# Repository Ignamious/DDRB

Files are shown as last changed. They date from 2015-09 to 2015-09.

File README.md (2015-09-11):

# DDRB 
This is a Digital Decade Resistor Box. This is the same as a Decade Resistor box, but uses an Arduino with LCD and Keypad to set the value. This will also allow the user to check the box and insure it's still within spec.

List of Features
  - LCD Readout of Resistance
  - Keypad to set resistance
  - Sub Ohm of .01 - .99 
  - Ohm 2^30 of Resistance ≈ 1,073,741,824 Ohms
  - Modular Cards, Easily replacable for Increased precistion (with Increase of Cst to the board)
  - 2 Expanstion Slots, Each with three Pins to the MCU (Future Expanstion) Signal Does Pass through these.
    - Possible uses
      - reading resistance from start to finish (will require slight rework of Buss Board)
      - Altering Resistance to give "True" value
      - Pulsed Output such as Sig Gen using Resistance values.
  - uses Binary Resistance values to get final resuslts:
    - 1 ohm + 2 ohm + 8 ohm = 11 ohms of resistance ECT. 
      - Should reduce cost

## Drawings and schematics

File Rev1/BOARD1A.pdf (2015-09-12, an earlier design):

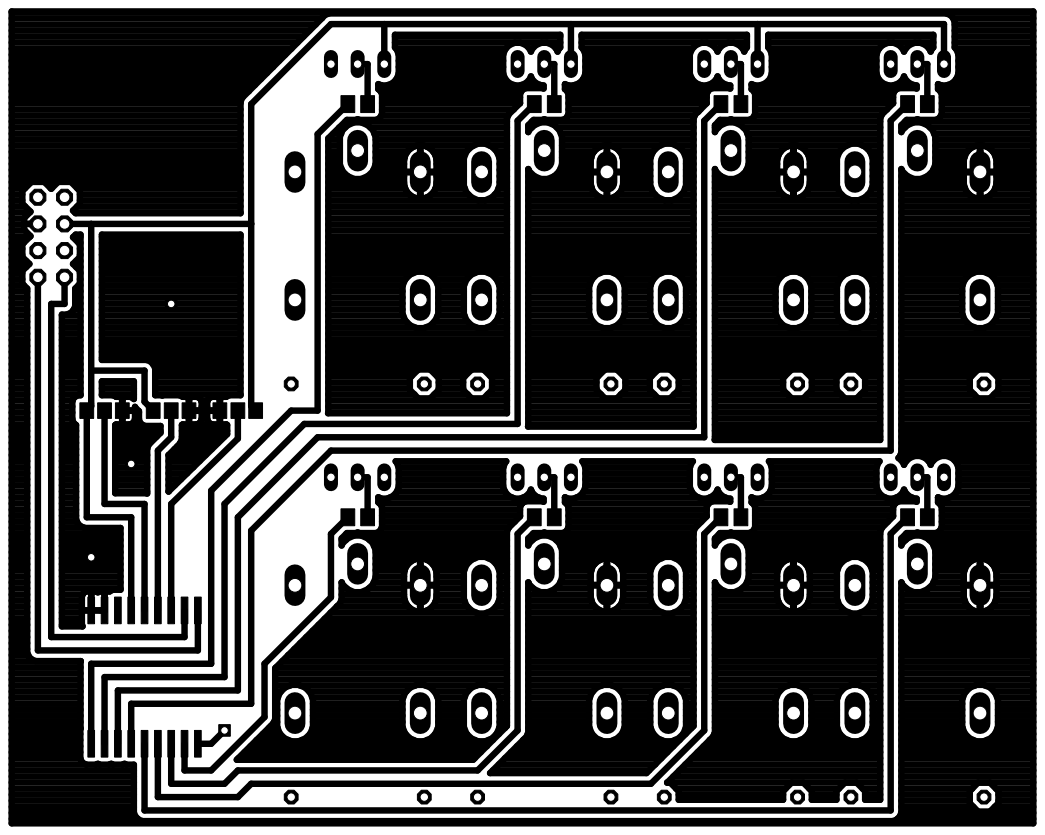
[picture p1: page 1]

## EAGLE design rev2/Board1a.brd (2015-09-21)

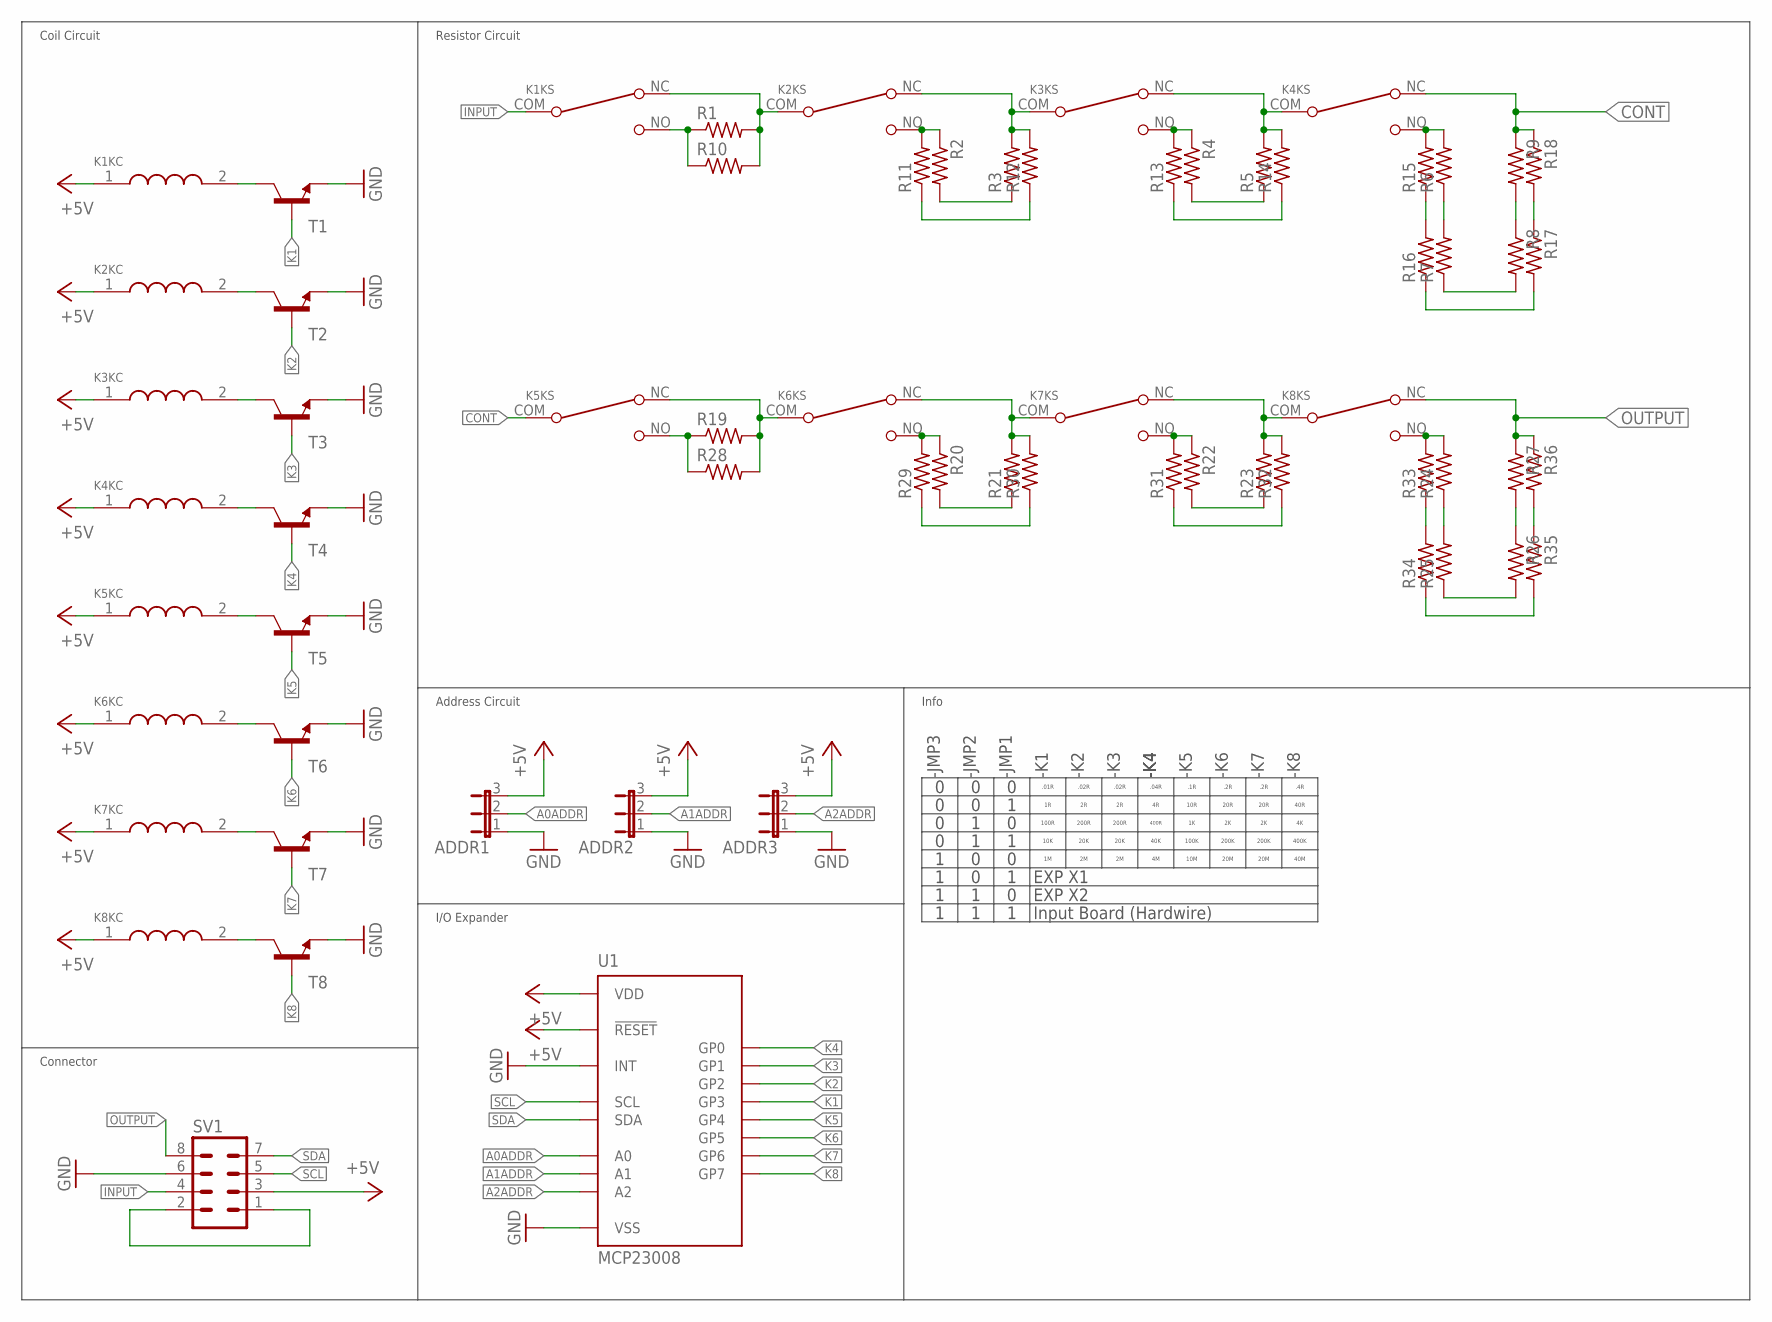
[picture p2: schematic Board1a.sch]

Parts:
ADDR1, ADDR2, ADDR3: JP2E; JP2
K1, K5: G5LE-1-VD DC12; G5LE
K2, K3, K4, K6, K7, K8: G5LE
R1, R2, R3, R4, R5, R6, R7, R8, R9, R19, R20, R21, R22, R23, R24, R25, R26, R27: R-US_0613/5V; P0613V
R10, R11, R12, R13, R14, R15, R16, R17, R18, R28, R29, R30, R31, R32, R33, R34, R35, R36: R-US_M1206; M1206
SV1: MA04-2
T1, T2, T3, T4, T5, T6, T7, T8: MMUN2211LT1-NPN-SC59-BEC; SC59-BEC
U1: MCP23008; SOIC

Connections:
+5V: ADDR1.3, ADDR2.3, ADDR3.3, K1.1 (COILA), K2.1 (COILA), K3.1 (COILA), K4.1 (COILA), K5.1 (COILA), K6.1 (COILA), K7.1 (COILA), K8.1 (COILA), SV1.3, U1.P$6 (!RESET), U1.P$18 (VDD)
A0ADDR: ADDR1.2, U1.P$5 (A0)
A1ADDR: ADDR2.2, U1.P$4 (A1)
A2ADDR: ADDR3.2, U1.P$3 (A2)
CONT: K4.NC, K5.COM, R9.1, R18.1
GND: ADDR1.1, ADDR2.1, ADDR3.1, SV1.6, T1.E, T2.E, T3.E, T4.E, T5.E, T6.E, T7.E, T8.E, U1.P$8 (INT), U1.P$9 (VSS)
INPUT: K1.COM, SV1.4
K1: T1.B, U1.P$13 (GP3)
K2: T2.B, U1.P$12 (GP2)
K3: T3.B, U1.P$11 (GP1)
K4: T4.B, U1.P$10 (GP0)
K5: T5.B, U1.P$14 (GP4)
K6: T6.B, U1.P$15 (GP5)
K7: T7.B, U1.P$16 (GP6)
K8: T8.B, U1.P$17 (GP7)
unnamed: K1.NO, R1.1, R10.1
unnamed: K1.NC, K2.COM, R1.2, R10.2
unnamed: R2.2, R3.1
unnamed: K2.NC, K3.COM, R3.2, R12.2
unnamed: SV1.1, SV1.2
unnamed: K2.NO, R2.1, R11.2
unnamed: K3.NC, K4.COM, R5.2, R14.2
unnamed: K3.NO, R4.1, R13.2
unnamed: K4.NO, R6.2, R15.2
unnamed: R4.2, R5.1
unnamed: K3.2 (COILB), T3.C
unnamed: R6.1, R7.2
unnamed: K1.2 (COILB), T1.C
unnamed: R7.1, R8.2
unnamed: K2.2 (COILB), T2.C
unnamed: R8.1, R9.2
unnamed: K4.2 (COILB), T4.C
unnamed: R15.1, R16.2
unnamed: R16.1, R17.2
unnamed: R17.1, R18.2
unnamed: R11.1, R12.1
unnamed: R13.1, R14.1
unnamed: K5.NC, K6.COM, R19.2, R28.2
unnamed: K6.NC, K7.COM, R21.2, R30.2
unnamed: K7.NC, K8.COM, R23.2, R32.2
unnamed: K5.NO, R19.1, R28.1
unnamed: R20.2, R21.1
unnamed: K6.NO, R20.1, R29.2
unnamed: K7.NO, R22.1, R31.2
unnamed: R22.2, R23.1
unnamed: K8.NO, R24.2, R33.2
unnamed: R24.1, R25.2
unnamed: R25.1, R26.2
unnamed: R26.1, R27.2
unnamed: R33.1, R34.2
unnamed: R34.1, R35.2
unnamed: R35.1, R36.2
unnamed: R29.1, R30.1
unnamed: R31.1, R32.1
unnamed: K7.2 (COILB), T7.C
unnamed: K5.2 (COILB), T5.C
unnamed: K6.2 (COILB), T6.C
unnamed: K8.2 (COILB), T8.C
OUTPUT: K8.NC, R27.1, R36.1, SV1.8
SCL: SV1.5, U1.P$1 (SCL)
SDA: SV1.7, U1.P$2 (SDA)

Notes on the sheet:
-JMP3
-JMP2
-JMP1
-K1
-K2
-K3
-K4
.01R
.1R
.02R
.04R
.2R
.4R
10R
100R
20R
200R
40R
400R
10K
100K
20K
200K
40K
400K
-K5
-K6
-K7
-K8
Coil Circuit
Connector
Resistor Circuit
Address Circuit
I/O Expander
Info
10M
20M
40M
EXP X1
EXP X2

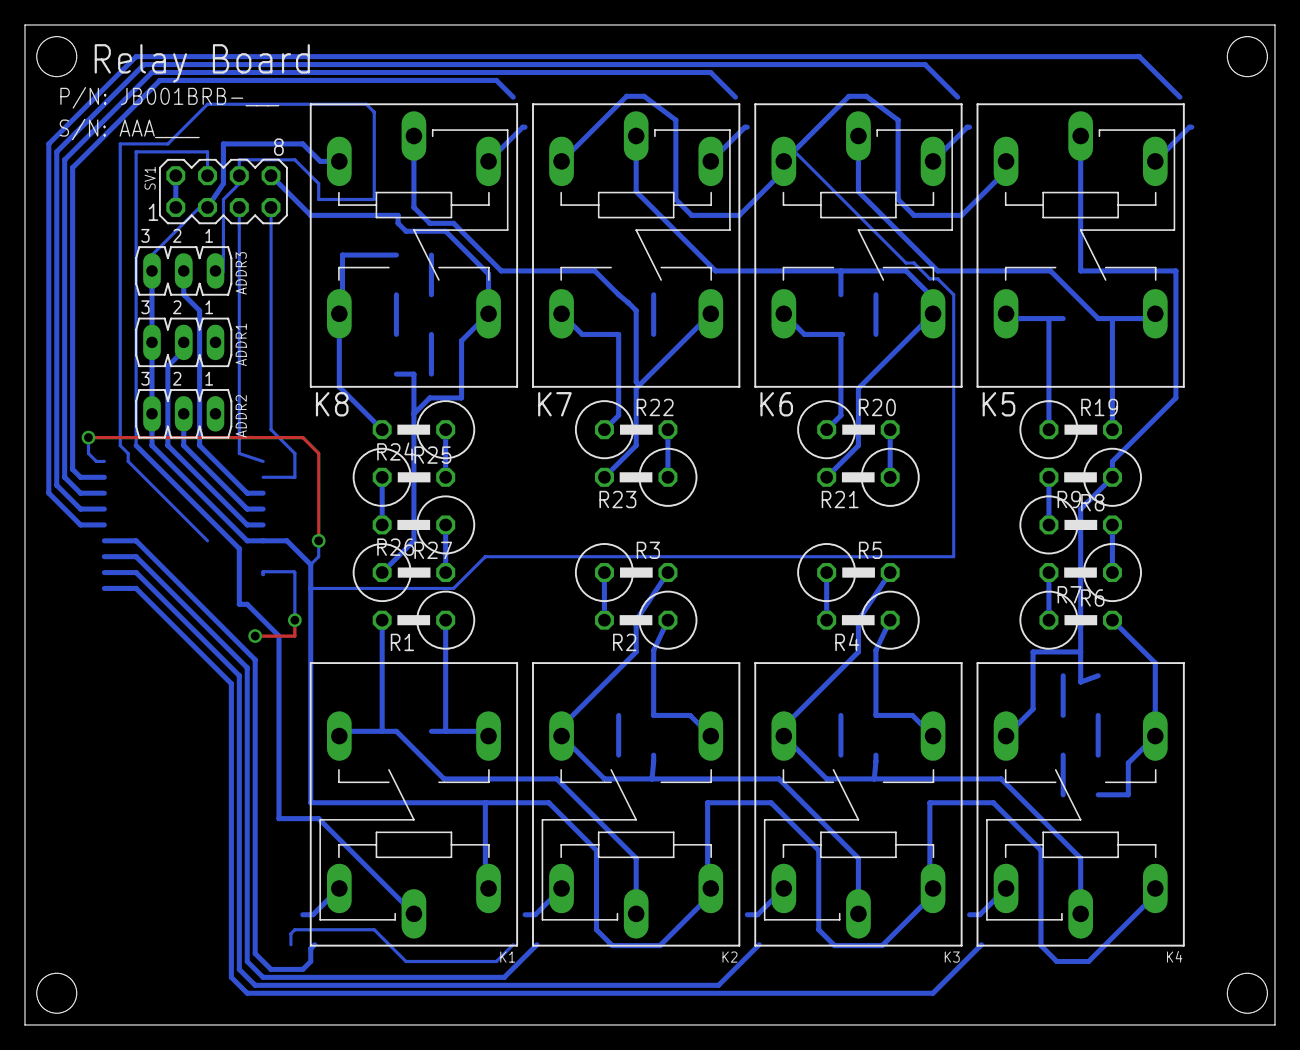
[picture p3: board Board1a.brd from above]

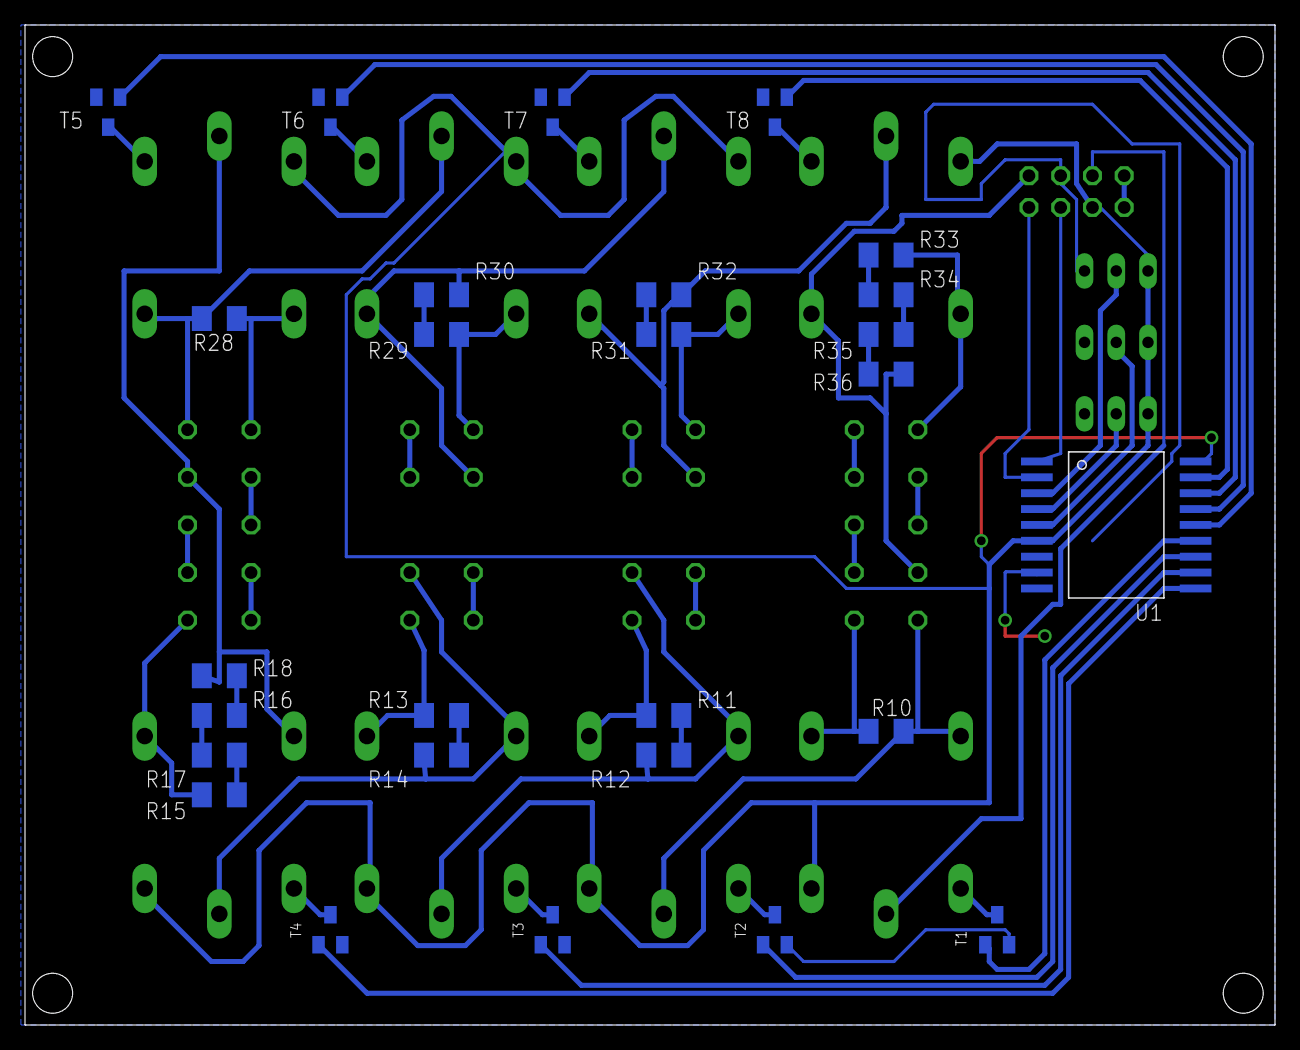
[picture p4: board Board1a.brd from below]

Board: 2 copper layers, 100.0 x 80.0 mm, 57 parts (27 on the bottom side), 61 nets.

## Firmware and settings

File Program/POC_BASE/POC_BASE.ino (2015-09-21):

/* All Posible Hex of Cards using MCP23008 With Address. Adress is:

| 0 | 1 | 0 | 0 | A2 | A1 | A0 | r=1/w=0 |

Full Hex  -   Board Address
0x40      -   000
0x42      -   001
0x44      -   010
0x46      -   011
0x48      -   100
0x4A      -   101
0x4C      -   110
0x4E      -   111


*/




//ADDRESS DEFS OF I2C IO EXPANDERS.
const byte SUB_OHM_BOARD_ADDRESS = 0x40;
const byte FISRT_BYTE_BOARD_ADDRESS = 0x42;
const byte SECOND_BYTE_BOARD_ADDRESS = 0x44;
const byte THIRD_BYTE_BOARD_ADDRESS = 0x46;
const byte FOURTH_BYTE_BOARD_ADDRESS = 0x48;
const byte FIRST_EXP_BOARD_ADDRESS = 0x4A;
const byte SECOND_EXP_BOARD_ADDRESS = 0x4C;
const byte MATRIX_BUTTON_4X4 = 0x4E;

//If using a different LCD then 16x4 code will need to be changed to account for it.
//Use following defs to change values as needed. Program will require at min a 16x2 screen.
//Note however that ROW 1 and 2 are used on the base and 3/4 are reserved for EX cards 1/2 (not implemented yet)
//However the options will utilise ROW 3/4 as well as the Cal check

//PIN DEFS FOR LCD 1
const byte LCD1_RS_PIN = 1;
const byte LCD1_Enable_Pin = 2;
const byte LCD1_D4_PIN = 3;
const byte LCD1_D5_PIN = 4;
const byte LCD1_D6_PIN = 5;
const byte LCD1_D7_PIN = 6;
const byte LCD1_COLUMN_COUNT = 16;
const byte LCD1_ROW_COUNT = 4;

/*
//PIN DEFS FOR LCD 2 (IF USED REMOVE COMMENT BLOCK)
const byte LCD2_RS_PIN = 1;
const byte LCD2_Enable_Pin = 2;
const byte LCD2_D4_PIN = 3;
const byte LCD2_D5_PIN = 4;
const byte LCD2_D6_PIN = 5;
const byte LCD2_D7_PIN = 6;
const byte LCD2_COLUMN_COUNT = 16;
const byte LCD2_ROW_COUNT = 4;
*/

#include <Wire.h>
#include <LiquidCrystal.h>

//OBJECT SETUP
LiquidCrystal MAIN_LCD(LCD1_RS_PIN, LCD1_Enable_Pin, LCD1_D4_PIN, LCD1_D5_PIN, LCD1_D6_PIN, LCD1_D7_PIN);

void setup() {
  // put your setup code here, to run once:
  Wire.begin();
  MAIN_LCD.begin(LCD1_COLUMN_COUNT, LCD1_ROW_COUNT);

  STARTUPSEQUINCE();
}

void loop() {
  // put your main code here, to run repeatedly:

}

void MAINLCDPREP() {
  MAIN_LCD.clear();
  MAIN_LCD.noAutoscroll();
  MAIN_LCD.setCursor(0, 0);
  MAIN_LCD.print("LOADING PREFS");
}

void CALIBRATION_CHECK() {
  MAIN_LCD.clear();
  MAIN_LCD.noAutoscroll();
  MAIN_LCD.setCursor(0, 0);
  MAIN_LCD.print("CAL CHECK:");
  MAIN_LCD.setCursor(0, 1);
  MAIN_LCD.print("ZERO DMM");
  MAIN_LCD.setCursor(0, 2);
  MAIN_LCD.print("INSERT LEADS");
  MAIN_LCD.setCursor(0, 3);
  MAIN_LCD.print("PRESS # TO CONT");
  while (1) {
    //wait for # to be pressed code
  }


}

void STARTUPSEQUINCE() {
  MAINLCDPREP();
  ZERO_ALL_RELAYS();
}

void ZERO_ALL_RELAYS() {
  Wire.beginTransmission(SUB_OHM_BOARD_ADDRESS);
  Wire.write(0x00);
  Wire.endTransmission();
  Wire.beginTransmission(FISRT_BYTE_BOARD_ADDRESS);
  Wire.write(0x00);
  Wire.endTransmission();
  Wire.beginTransmission(SECOND_BYTE_BOARD_ADDRESS);
  Wire.write(0x00);
  Wire.endTransmission();
  Wire.beginTransmission(THIRD_BYTE_BOARD_ADDRESS);
  Wire.write(0x00);
  Wire.endTransmission();
  Wire.beginTransmission(FOURTH_BYTE_BOARD_ADDRESS);
  Wire.write(0x00);
  Wire.endTransmission();
}

void FIRST_STARTUP() {
  MAIN_LCD.clear();
  MAIN_LCD.noAutoscroll();
  MAIN_LCD.setCursor(0, 0);
  MAIN_LCD.print("FIRST STARTUP");
  CALIBRATION_CHECK(); 

}

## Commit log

2015-09-11 First Upload
    The First upload to my DDRB
    [BOARD1A.brd, BOARD1A.sch, BusBoard 2.sch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]
2015-09-12 Added Silk Screens, Changed Layout some.
    [BOARD1A.brd]
2015-09-14 Changed Parts
    Changed relay from 5VDC Coil to 12 VDC so it’s only 40mA. Changed to
    SOT-23 SBT Transistor (100mA capability). removed bias resistors.
    [BOARD1A.brd, BOARD1A.sch]
2015-09-18 Updated Design Rev2 Current
    Current Design is now Rev 2. At this time looks like i can get all the
    parts needed to do this one.
    [BOARD1A.brd, BOARD1A.sch, Board1a.brd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]
2015-09-21 more work
    [Board1a.brd, Board1a.sch, BusBoard 2.sch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]

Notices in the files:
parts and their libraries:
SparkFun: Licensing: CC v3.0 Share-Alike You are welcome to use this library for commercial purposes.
